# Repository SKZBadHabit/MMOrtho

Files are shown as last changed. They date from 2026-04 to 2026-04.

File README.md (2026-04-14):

# MMOrtho

**Custom 60-key ortholinear keyboard — firmware, hardware, and web configurator**

_Raspberry Pi Pico 2 W · CircuitPython · WiFi · OLED · Browser-based config_

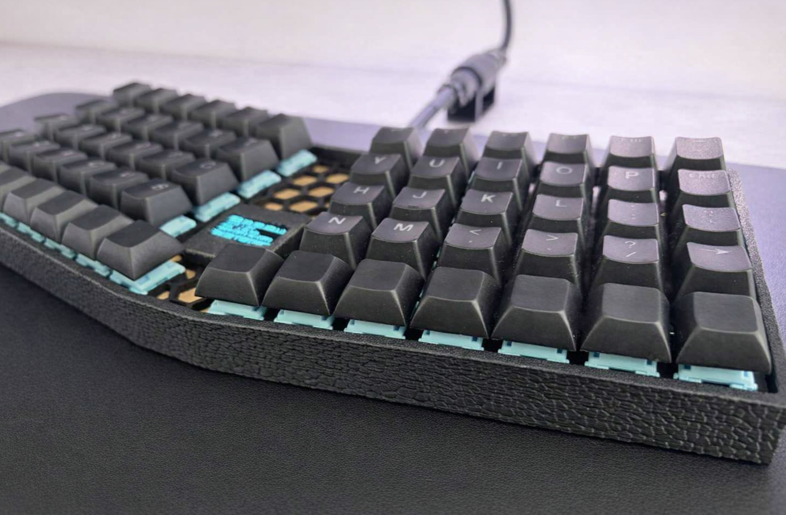
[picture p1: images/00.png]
MMOrtho keyboard


---

## Highlights

- **~1000 Hz scan rate** — rock-solid 9 ms debounce, zero missed keystrokes
- **128×64 OLED dashboard** — 4 live tabs: Status, System, Network, Weather
- **WiFi integrated** — NTP clock, live weather (wttr.in), Home Assistant sync
- **Macro engine** — 8 slots: text strings, key combos, mouse clicks, multi-step sequences
- **Mouse emulation** — left/right buttons, scroll, 100 Hz autoclicker, media controls
- **Web Configurator** — remap keys, edit macros, configure WiFi — all in the browser, no PC tools needed
- **Production-hardened boot** — USB drive and serial disabled by default for security
- **3D-printed case** — full Fusion 360 and STL files included

---

## Hardware

| Component | Spec |
| --- | --- |
| MCU | Raspberry Pi Pico 2 W (RP2350, dual-core @ 150 MHz) |
| Wireless  | CYW43439 2.4 GHz WiFi (onboard) |
| Display | SSD1306 OLED 128×64 px via I2C |
| Matrix | 5 × 12 ortholinear (60 keys) + 2 thumb keys (E18, E19) |
| Scan rate | ~1000 Hz |
| Debounce  | 9 ms |

### Pin Assignments

| Signal | GPIO |
| --- | --- |
| Matrix columns (12) | GP10–GP15, GP16–GP21 |
| Matrix rows (5) | GP0–GP4 |
| Extra key E18 | GP9 |
| Extra key E19 | GP22 |
| Display SDA | GP26 |
| Display SCL | GP27 |

---

## 3D-Printed Case

MMOrtho is a **fully open-source keyboard** — the case is designed to be 3D printed at home.
All CAD files are in the [`hardware/`](hardware/) folder.

| File | Format | Use |
| ---- | --- | --- |
| `MMOrtho.stl` | STL | Standard 3D printing (any slicer) |
| `MMOrtho.3mf` | 3MF | Pre-configured print settings included |
| `MMOrtho.step` | STEP | Import into any CAD tool |
| `MMOrtho.f3d` | Fusion 360 | Fully editable native project |

> **Tip:** Use the `.3mf` file for best results — it includes print orientation and settings.

### Bill of Materials

Everything you need to build one MMOrtho:

| Qty | Part | Notes |
| --- | ---- | ----- |
| 1 | Raspberry Pi Pico 2 W (RP2350) | The RP2350-based W variant with onboard WiFi |
| 1 | SSD1306 OLED Display 128×64 | I2C interface, 4-pin |
| 1 | USB-C Breakout Board | Wired to Pico VBUS/GND for power input |
| 62 | MX-compatible switches | 60 matrix + 2 thumb keys (E18/E19) |
| 62 | Keycaps | MX stem, any profile (e.g. XDA, DSA, OEM) |
| 4 | M3 × 10 mm screws | Case assembly |
| 4 | M3 hex nuts | Case assembly |
| 1 | 3D-printed case | Print from `hardware/MMOrtho.3mf` |

---

## Key Layout

### Base Layer

```
┌────┬───┬───┬───┬───┬───┐           ┌───┬───┬───┬───┬───┬────┐
│ESC │ 1 │ 2 │ 3 │ 4 │ 5 │           │ 6 │ 7 │ 8 │ 9 │ 0 │BSP │
├────┼───┼───┼───┼───┼───┤           ├───┼───┼───┼───┼───┼────┤
│TAB │ Q │ W │ E │ R │ T │           │ Y │ U │ I │ O │ P │ \  │
├────┼───┼───┼───┼───┼───┤           ├───┼───┼───┼───┼───┼────┤
│LTG │ A │ S │ D │ F │ G │           │ H │ J │ K │ L │ ; │ '  │
├────┼───┼───┼───┼───┼───┤           ├───┼───┼───┼───┼───┼────┤
│SFT │ Z │ X │ C │ V │ B │           │ N │ M │ , │ . │ / │SFT │
├────┼───┼───┼───┼───┼───┼───────────┼───┼───┼───┼───┼───┼────┤
│CTL │WIN│ALT│AGR│SPC│FN │ E19   E18 │SPC│ENT│ ^ │ = │ [ │ ]  │
└────┴───┴───┴───┴───┴───┴───────────┴───┴───┴───┴───┴───┴────┘
```

### FN Layer (hold FN)

| Shortcut | Action | Shortcut | Action |
| --- | --- | --- | --- |
| FN + I/K/J/L | Arrow keys | FN + W | WiFi toggle |
| FN + R / F | Scroll up / down | FN + , | WiFi Setup Wizard |
| FN + B / G | Mouse left / right click | FN + . | Cycle OLED tab |
| FN + A | Autoclicker toggle | FN + [ / ] | Volume down / up  |
| FN + M | Mute | FN + P | System reset |
| FN + O | Page Up | FN + ; | Show statistics |
| FN + E18 | Web Configurator | | |

---

## OLED Dashboard

Switch tabs with **FN + .**

| Tab | Content |
| --- | --- |
| **STS** | KPM, uptime, Caps Lock, autoclicker state, WiFi, CPU temp |
| **SYS** | Live bars — CPU temp, voltage, scan rate |
| **NET** | WiFi signal, Home Assistant entity states |
| **WTR** | NTP clock with auto-DST + local weather from wttr.in |

---

## Boot Modes

| Mode | Trigger | USB Drive | USB Serial | HID |
| --- | --- | --- | --- | --- |
| Production  | Normal plug-in | Off | Off | On  |
| Development | Hold E18 at plug-in | On | On | On  |

> **Note:** Never use Development mode in public — the full firmware filesystem is exposed via USB mass storage.

---

## Macro Engine

Create macros in the Web Configurator and assign them to any key (M1–M8).

| Type | Description |
| --- | --- |
| **Text** | Types a string character by character |
| **Combo** | Presses multiple keys simultaneously (e.g. Ctrl+Shift+T) |
| **Mouse** | Fires a mouse button click or scroll action |
| **Sequence** | Multi-step: mix text, combos, mouse actions, and delays  |

---

## Web Configurator

Activate with **FN + M** (WiFi must be connected).
Open the IP shown on the OLED in any browser on the same network.

| Tab | What you can do |
| --- | --- |
| Docs | Full documentation rendered live |
| Keymap | Remap all keys across Base and FN layers |
| Macros | Create, edit, delete macros — all 4 types |
| Settings | Timing, Home Assistant, weather, NTP timezone |
| Network | Scan and connect to WiFi networks |
| Statistics | All-time keypresses, runtime, KPM, IP address |

---

## Power Management

| Level | Trigger | Effect |
| --- | --- | --- |
| Display sleep | 210 s idle | OLED turns off |
| Deep idle | 30 min idle  | WiFi off, scan rate reduced |
| Wake | Any keypress | Instant full restore |

---

## Repository Structure

```
MMOrtho/
├── firmware/               # CircuitPython source code
│   ├── boot.py             # Boot mode selector
│   ├── code.py             # Main entry point & async event loop
│   ├── config.py           # Hardware pins, timing, API config
│   ├── keymap.py           # QMK-style layer definitions
│   ├── i2cdisplaybus.py    # Display bus compatibility wrapper
│   ├── features/           # Modular feature system
│   │   ├── keyboard.py     # Matrix scanning engine
│   │   ├── display.py      # OLED dashboard (4 tabs)
│   │   ├── macros.py       # Macro engine
│   │   ├── webserver.py    # HTTP server + REST API
│   │   ├── wifi.py         # WiFi, NTP, weather, Home Assistant
│   │   ├── mouse.py        # Mouse emulation & autoclicker
│   │   ├── power.py        # Power management & sleep
│   │   └── storage.py      # JSON-based persistent statistics
│   └── web/
│       └── index.html      # Web Configurator (single-page app)
│
├── hardware/               # 3D CAD files
│   ├── MMOrtho.3mf         # 3MF — optimized for 3D printing
│   ├── MMOrtho.stl         # STL — standard 3D printing format
│   ├── MMOrtho.step        # STEP — CAD-agnostic exchange format
│   └── MMOrtho.f3d         # Fusion 360 native project
│
├── libs/                   # CircuitPython library dependencies
│   └── (adafruit libraries — copy to CIRCUITPY/lib/)
│
├── images/                 # Product photos
│
└── docs/
    ├── SETUP.md            # Step-by-step installation guide
    └── TROUBLESHOOTING.md  # Common issues and fixes
```

---

## Getting Started

See [docs/SETUP.md](docs/SETUP.md) for the full installation guide.

**Quick summary:**

1. Flash CircuitPython to Pico 2 W
2. Copy `libs/` → `CIRCUITPY/lib/`
3. Copy `firmware/` contents → `CIRCUITPY/`
4. Edit `config.py` with your Home Assistant URL/token and city
5. Plug in — keyboard is ready
6. Use **FN + ,** to connect WiFi via the interactive wizard

---

## Photos

<table>
<tr>
<td>MMOrtho front view</td>
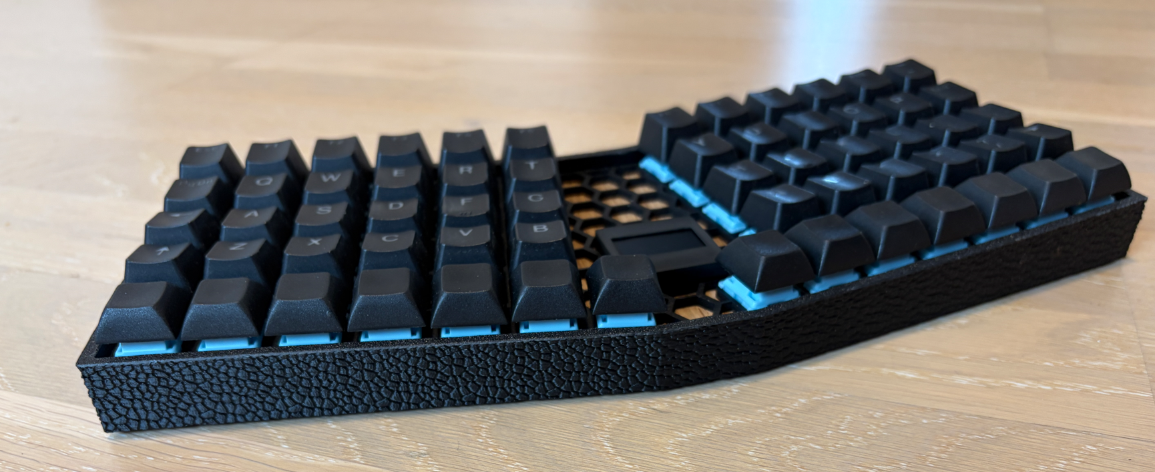
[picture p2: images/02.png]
MMOrtho side view
<td></td>
</tr>
<tr>
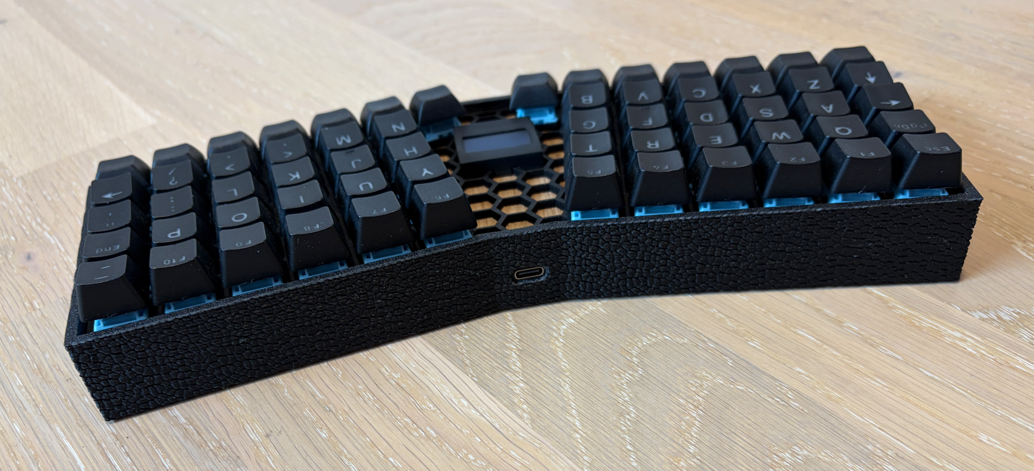
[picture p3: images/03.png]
MMOrtho OLED display
<td></td>
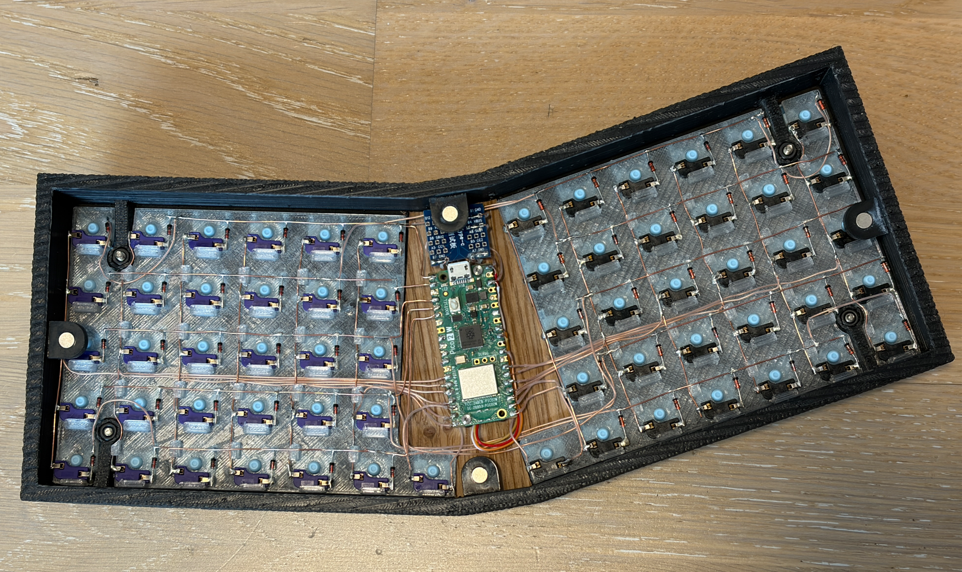
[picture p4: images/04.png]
MMOrtho internals
<td></td>
</tr>
<tr>
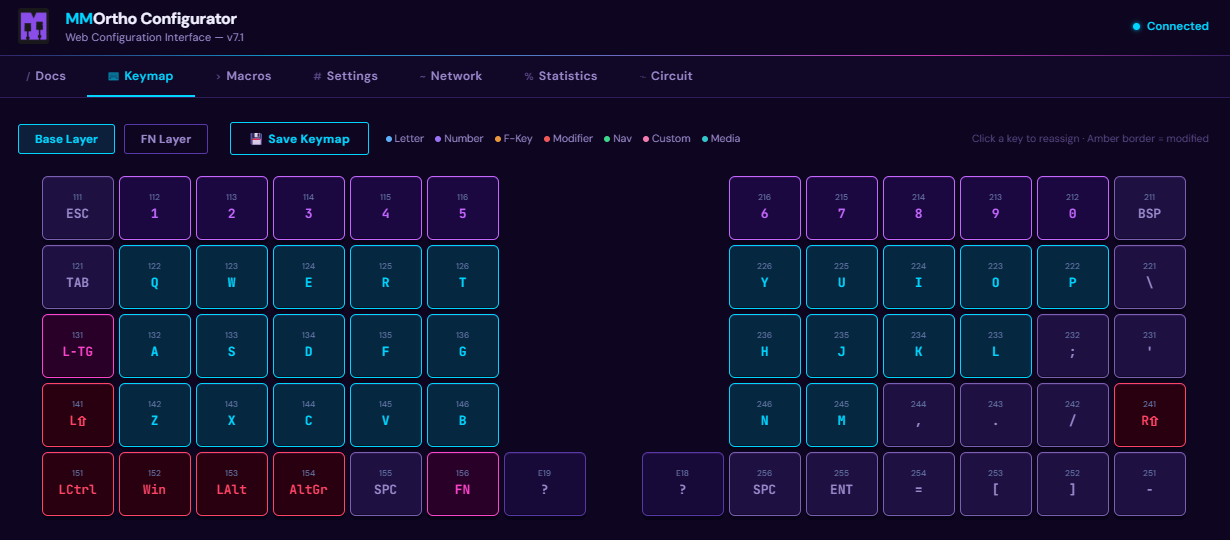
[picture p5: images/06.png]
Hand-wiring detail
<td></td>
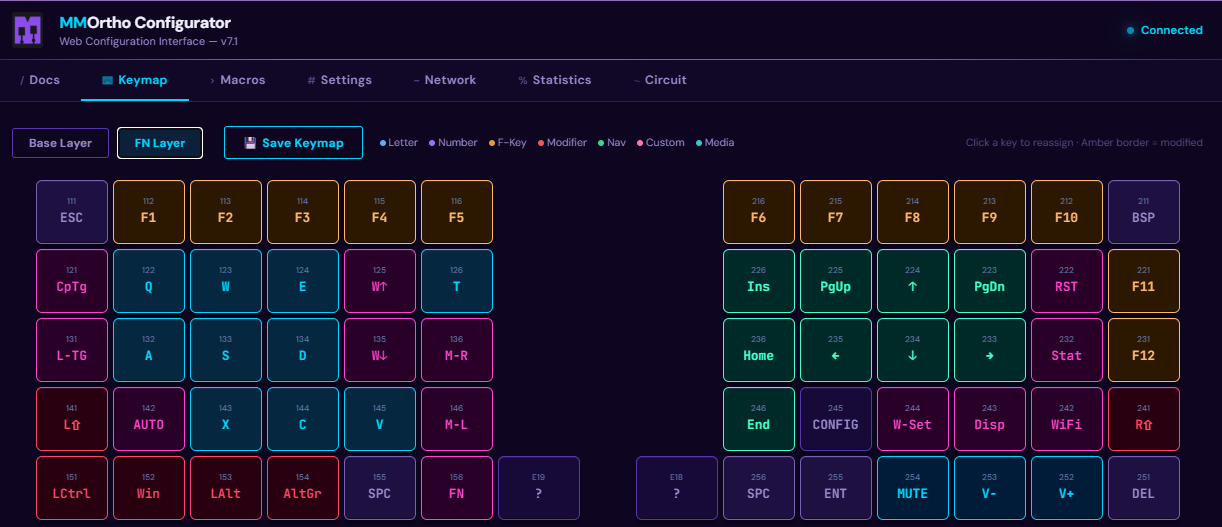
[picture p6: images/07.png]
Kailh Hotswap Socket clips
<td></td>
</tr>
<tr>
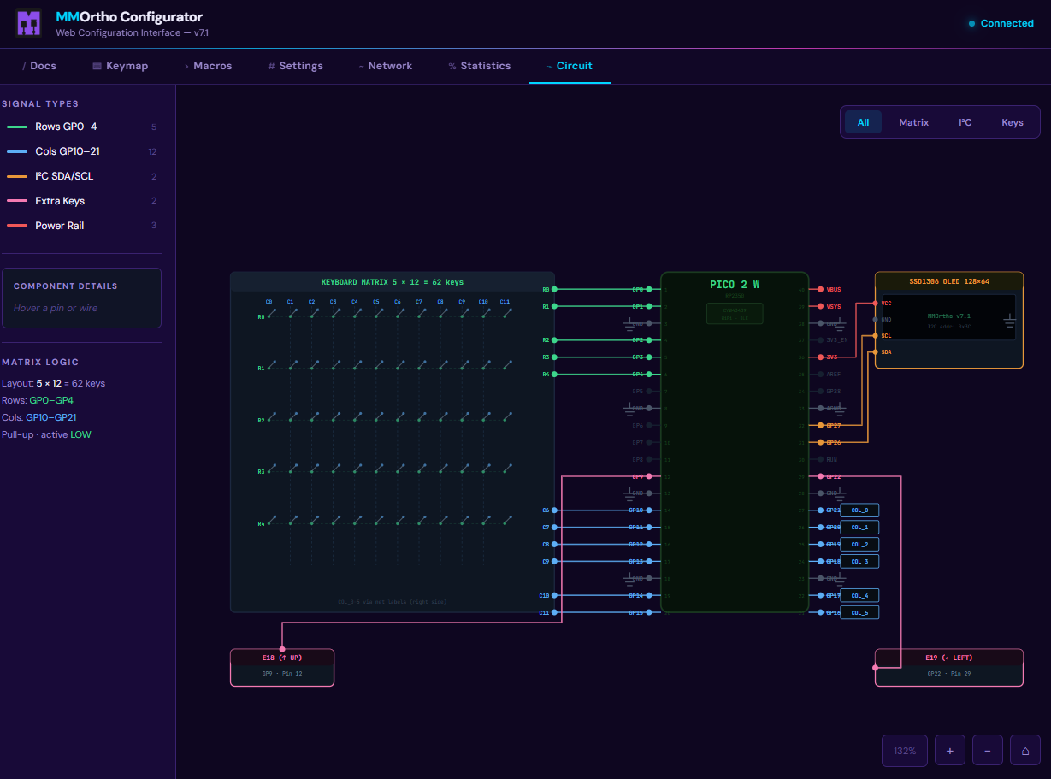
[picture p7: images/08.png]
Assembled keyboard profile
<td colspan="2" align="center"></td>
</tr>
</table>

---

## License

MIT License — see [LICENSE](LICENSE) for details.

Developed by **Bad Habit**

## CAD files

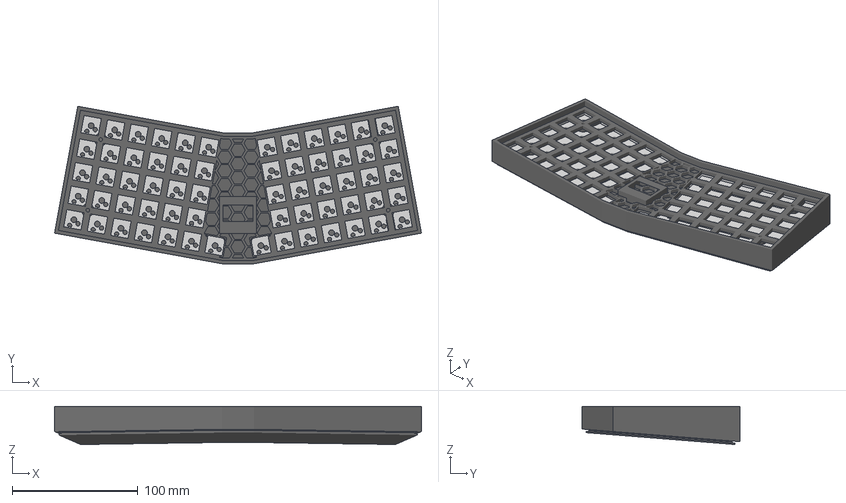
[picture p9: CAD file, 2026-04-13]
hardware/MMOrtho.3mf
292.4 x 125.5 x 30.3 mm
Aussen
BasePlate
BasePlateHalter (1) (1)
BasePlateHalter (1)
BasePlateHalter (2)
BasePlateHalter
Boden
DisplayWabe_neueDisplays
FullPlate_left
FullPlate_right (1)
Innen
PCB-Distanzhalter_Right
PCB-Distanzhalter_left
Pi_Pico_Glue_Mount_-_Plate
USB_inlay
WabenBackground

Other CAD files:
hardware/MMOrtho.stl

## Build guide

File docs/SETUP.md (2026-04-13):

# Setup Guide

## Requirements

- Raspberry Pi Pico 2 W (RP2350)
- SSD1306 OLED display (128×64, I2C)
- Custom PCB or hand-wired 5×12 matrix + 2 thumb keys
- USB-C cable for flashing

---

## Step 1 — Flash CircuitPython

1. Download the latest **CircuitPython UF2** for Raspberry Pi Pico 2 W from:
   [circuitpython.org/board/raspberry_pi_pico2_w](https://circuitpython.org/board/raspberry_pi_pico2_w)

2. Hold the **BOOTSEL** button on the Pico 2 W and plug it into USB.
   The device mounts as `RPI-RP2`.

3. Drag & drop the `.uf2` file onto `RPI-RP2`.
   The Pico reboots and mounts as `CIRCUITPY`.

---

## Step 2 — Install Libraries

Copy the entire `libs/` folder from this repository to the `lib/` folder on `CIRCUITPY`:

```
CIRCUITPY/
└── lib/
    ├── adafruit_hid/
    ├── adafruit_httpserver/
    ├── adafruit_display_text/
    ├── adafruit_display_shapes/
    ├── adafruit_displayio_ssd1306.mpy
    ├── adafruit_connection_manager.mpy
    ├── adafruit_matrixkeypad.mpy
    ├── adafruit_requests.mpy
    ├── adafruit_ntp.mpy
    ├── adafruit_ticks.mpy
    └── asyncio/
```

---

## Step 3 — Configure the Firmware

1. Copy `firmware/config.py` to `CIRCUITPY/config.py`.

2. Edit `config.py` and set your values:

   | Setting | Description |
   |---------|-------------|
   | `HomeAssistant.URL` | Your Home Assistant IP and port |
   | `HomeAssistant.TOKEN` | Long-Lived Access Token (HA → Profile → Security) |
   | `HomeAssistant.ENTITIES` | Entity IDs to monitor on the NET tab |
   | `WeatherConfig.CITY` | Your city name for wttr.in weather |
   | `WeatherConfig.NTP_TZ_OFFSET` | UTC offset (e.g. `1` for CET, `2` for CEST) |

   > Home Assistant integration is optional — leave TOKEN empty to disable it.

---

## Step 4 — Copy Firmware Files

Copy these files/folders from `firmware/` to the root of `CIRCUITPY`:

```
CIRCUITPY/
├── boot.py
├── code.py
├── config.py          ← your edited version
├── keymap.py
├── i2cdisplaybus.py
├── features/
└── web/
```

---

## Step 5 — First Boot

Unplug and replug the keyboard (without holding any key).

The keyboard boots in **Production Mode**:
- USB drive is hidden
- USB serial is disabled
- USB HID is active — the keyboard works immediately

---

## Step 6 — WiFi Setup

1. Hold **FN** and press **,** (comma) to start the WiFi Setup Wizard.
2. The OLED display guides you through entering your SSID and password using the keyboard.
3. Credentials are saved encrypted to `/data/wifi.json` on the device.

---

## Step 7 — Web Configurator

1. Make sure WiFi is connected (NET tab shows an IP address).
2. Hold **FN** and press **E18** to start Config Mode.
3. Open a browser on any device on the same network and go to the IP shown on the OLED.
4. The Web Configurator loads — remap keys, create macros, adjust settings.

---

## Development Mode

To edit firmware files after first setup:

1. Hold **E18** and plug the keyboard into USB.
2. The keyboard boots in **Development Mode** — `CIRCUITPY` drive and USB serial are accessible.
3. Edit files normally. CircuitPython auto-restarts on save.
4. Unplug and replug (without holding E18) to return to Production Mode.

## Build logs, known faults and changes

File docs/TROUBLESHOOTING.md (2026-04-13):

# Troubleshooting

## Keyboard not recognized as HID device

**Symptom:** PC shows no keyboard after plugging in.

- Make sure you booted in **Production Mode** (no key held at plug-in).
- Verify `boot.py` is on `CIRCUITPY` root.
- Check that `adafruit_hid` library is in `lib/`.

---

## OLED display stays blank

**Symptom:** Display never lights up.

- Verify I2C wiring: SDA → GP26, SCL → GP27.
- Confirm the display address is `0x3C` (scan with `import busio; i2c = busio.I2C(...); i2c.scan()`).
- Check that `adafruit_displayio_ssd1306.mpy` is in `lib/`.

---

## WiFi not connecting

**Symptom:** WiFi icon shows disconnected, no IP on NET tab.

- Run the **WiFi Setup Wizard** again: **FN + ,**
- Ensure the SSID is 2.4 GHz (Pico 2 W does not support 5 GHz).
- Delete `/data/wifi.json` from CIRCUITPY (Development Mode) and re-run the wizard.

---

## Web Configurator not loading

**Symptom:** Browser shows "connection refused" or times out.

- WiFi must be connected first — check NET tab for an IP.
- Make sure `web/index.html` is on `CIRCUITPY/web/index.html`.
- Check `adafruit_httpserver` is in `lib/`.
- Try a different browser or disable browser extensions.

---

## Keys not registering / wrong keys

**Symptom:** Key presses are missed or wrong character appears.

- Check matrix wiring matches the pin assignments in `config.py`.
- Verify the keymap in `keymap.py` matches your physical layout.
- Use the **Web Configurator → Keymap** tab to remap keys without editing code.

---

## Home Assistant entities not showing

**Symptom:** NET tab shows `--` for entity states.

- Verify `HomeAssistant.URL` and `HomeAssistant.TOKEN` in `config.py`.
- Generate a new Long-Lived Access Token in HA: **Profile → Security → Long-Lived Access Tokens**.
- Check that entity IDs in `HomeAssistant.ENTITIES` exactly match those in HA.

---

## Firmware crash / constant reboot loop

**Symptom:** OLED flickers, keyboard constantly resets.

1. Boot into **Development Mode** (hold E18 at plug-in).
2. Open a serial terminal (115200 baud) — e.g. Thonny or `screen /dev/ttyACM0 115200`.
3. Read the traceback printed to serial.
4. Fix the offending file and save — CircuitPython restarts automatically.

---

## Out of memory (MemoryError)

**Symptom:** Serial shows `MemoryError` after boot.

- Make sure all `.py` files in `features/` are not accidentally duplicated.
- Check for runaway string concatenation in macros or display code.
- The GC interval in `config.py` (`Timing.GC_INTERVAL`) can be lowered for more frequent collection.

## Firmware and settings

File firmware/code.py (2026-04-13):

# code.py - MMOrtho Keyboard Main Entry Point
# Modular Firmware for CircuitPython
#
# Version: 5.0
# Hardware: Raspberry Pi Pico2 W (RP2350)
# Author: Michael Mörtenhuber
#
# v5.0 Changes:
#   - Modern Dashboard UI with 3 switchable panels
#   - Redesigned Splash Screen
#   - Performance optimizations in main loop

import asyncio
import time
import traceback
import usb_hid
from adafruit_hid.keyboard import Keyboard
from adafruit_hid.mouse import Mouse
from adafruit_hid.consumer_control import ConsumerControl

# Config & Keymap
from config import KEYBOARD_NAME, CODE_VERSION, WeatherConfig
from keymap import KC

# Features
from features.keyboard import KeyboardEngine
from features.display import DisplayFeature, MODE_NETWORK
from features.storage import StorageFeature
from features.wifi import WiFiFeature
from features.mouse import MouseFeature
from features.power import PowerFeature
from features.webserver import WebServerFeature
from features.macros import MacroEngine


# =============================================================================
# HID SETUP
# =============================================================================

kbd = Keyboard(usb_hid.devices)
hid_mouse = Mouse(usb_hid.devices)
cc = ConsumerControl(usb_hid.devices)


# =============================================================================
# FEATURE INITIALIZATION
# =============================================================================

# Core Features
keyboard = KeyboardEngine(kbd)
display = DisplayFeature()
storage = StorageFeature()

# Optional Features
wifi = WiFiFeature()
mouse = MouseFeature(hid_mouse, cc)
power = PowerFeature(display, storage, wifi)
macro_engine = MacroEngine(kbd, hid_mouse)
webserver = WebServerFeature(wifi, storage, macro_engine)


# =============================================================================
# FEATURE WIRING (Connect Features Together)
# =============================================================================

def on_keypress():
    """Callback bei jedem Tastendruck"""
    storage.increment_keypress()
    power.activity()

    # Display State aktualisieren
    display.set_state("current_keypress", storage.current_keypress)


def on_layer_change(layer, toggled=False):
    """Callback bei Layer-Wechsel"""
    display.update_layer(layer, toggled)


def on_autoclicker_change(enabled):
    """Callback bei Autoclicker Toggle"""
    display.set_state("autoclicker", enabled)


def on_caps_change():
    """Callback bei Caps Lock Toggle"""
    display.update_caps(keyboard.caps_on)


# Wire up Callbacks
keyboard.on_keypress = on_keypress
keyboard.on_layer_change = on_layer_change
mouse.on_autoclicker_change = on_autoclicker_change


# =============================================================================
# CUSTOM KEY HANDLERS
# =============================================================================

def handle_mouse_left():
    """Handler für Mausklick links (Hold)"""
    mouse.left_press()


def handle_mouse_right():
    """Handler für Mausklick rechts (Hold)"""
    mouse.right_press()


def handle_show_stats():
    """Handler für Statistik-Anzeige"""
    storage.force_save()
    wifi.refresh_device_status()
    display.show_statistics(
        storage.alltime_keypress,
        storage.alltime_runtime,
        wifi.get_ip_address()
    )


def handle_display_mode():
    """Handler für Display-Modus Toggle"""
    display.toggle_mode()


def handle_wifi_toggle():
    """Handler für WiFi Toggle"""
    wifi.toggle()
    # Status an Display weitergeben
    status = wifi.get_status_dict()
    for key, value in status.items():
        display.set_state(key, value)


def handle_wifi_setup():
    """Handler für WiFi Setup Wizard (FN+,)"""
    if wifi.setup_active:
        return  # Wizard läuft bereits
    wifi.start_setup()
    keyboard.key_interceptor = wifi.handle_setup_key


def handle_config_mode():
    """
    Handler für FN + Right Shift → Configuration Mode Toggle.
    Im Config Mode zeigt das Display 'Configuration Mode' + IP-Adresse.
    Tastatur arbeitet normal weiter, nur das Display ändert sich.
    Zweiter Druck auf FN + Right Shift kehrt zum normalen Dashboard zurück.

    KEIN wifi.start_ap() hier — AP-Init blockiert 3-10s und friert die
    Tastatur ein. Config Mode setzt WiFi voraus (Setup-Wizard: FN+,).
    """
    if display.config_mode_active:
        # Config Mode beenden
        display.exit_config_mode()
        webserver.stop()
    else:
        # Config Mode aktivieren — nur wenn WiFi verbunden
        ip = wifi.get_ip_address()
        if ip == "Not connected":
            # Kein WiFi → Display-Hinweis aber kein Freeze durch AP-Init
            display.show_config_mode(None)
        else:
            display.show_config_mode(ip)
            webserver.start()


# Register Custom Key Handlers
keyboard.register_handler(KC.MOUSE_LEFT, handle_mouse_left)
keyboard.register_handler(KC.MOUSE_RIGHT, handle_mouse_right)
keyboard.register_handler(KC.MOUSE_WHEEL_UP, mouse.scroll_up)
keyboard.register_handler(KC.MOUSE_WHEEL_DOWN, mouse.scroll_down)
keyboard.register_handler(KC.AUTOCLICKER, mouse.toggle_autoclicker)
keyboard.register_handler(KC.WIFI_TOGGLE, handle_wifi_toggle)
keyboard.register_handler(KC.WIFI_SETUP, handle_wifi_setup)
keyboard.register_handler(KC.DISPLAY_MODE, handle_display_mode)
keyboard.register_handler(KC.SHOW_STATS, handle_show_stats)
keyboard.register_handler(KC.SYSTEM_RESET, storage.save_and_reset)
keyboard.register_handler(KC.CAPS_TOGGLE, on_caps_change)
keyboard.register_handler(KC.MUTE, mouse.mute)
keyboard.register_handler(KC.VOL_DOWN, mouse.volume_down)
keyboard.register_handler(KC.VOL_UP, mouse.volume_up)
keyboard.register_handler("KC_CONFIG_MODE", handle_config_mode)

# Macro Handlers (KC.MACRO_1 .. KC.MACRO_8 → macro IDs 1-8)
keyboard.register_handler(KC.MACRO_1, lambda: macro_engine.execute(1))
keyboard.register_handler(KC.MACRO_2, lambda: macro_engine.execute(2))
keyboard.register_handler(KC.MACRO_3, lambda: macro_engine.execute(3))
keyboard.register_handler(KC.MACRO_4, lambda: macro_engine.execute(4))
keyboard.register_handler(KC.MACRO_5, lambda: macro_engine.execute(5))
keyboard.register_handler(KC.MACRO_6, lambda: macro_engine.execute(6))
keyboard.register_handler(KC.MACRO_7, lambda: macro_engine.execute(7))
keyboard.register_handler(KC.MACRO_8, lambda: macro_engine.execute(8))


# =============================================================================
# DISPLAY STATE SYNC
# =============================================================================

def sync_display_state():
    """Synchronisiert alle State-Werte mit dem Display"""
    display.set_state("cpu_temp", power.get_cpu_temp())
    display.set_state("scan_rate", keyboard.scan_rate)
    display.set_state("autoclicker", mouse.autoclicker_on)
    display.set_state("voltage", power.get_voltage())
    display.set_state("caps_on", keyboard.caps_on)
    display.set_state("current_runtime", storage.get_live_runtime())

    # WiFi Status
    status = wifi.get_status_dict()
    for key, value in status.items():
        display.set_state(key, value)


# =============================================================================
# MAIN LOOP
# =============================================================================

async def main():
    """Haupt-Async-Loop - Optimized for v5.0"""
    print(f"\n{KEYBOARD_NAME} v{CODE_VERSION} starting...")

    # Splash Screen anzeigen
    display.splash_screen()

    # Warten auf Tastendruck
    print("Waiting for keypress...")
    keyboard.wait_for_keypress()

    # Main Screen aktivieren
    display.main_screen()
    sync_display_state()

    # Webserver Task starten
    asyncio.create_task(webserver.run_async())

    print("Keyboard active!")

    # === Timer Initialization ===
    current_time = time.monotonic()
    last_display_update = current_time
    last_runtime_update = current_time
    last_scroll_time = current_time
    last_weather_update = -WeatherConfig.REFRESH_INTERVAL  # Sofort beim ersten Loop holen

    # === Constants (avoid repeated lookups) ===
    SCROLL_REPEAT_INTERVAL = 0.05  # 50ms = 20 scrolls/sec
    DISPLAY_UPDATE_INTERVAL = 30.0
    RUNTIME_UPDATE_INTERVAL = 300.0

    # Cache key strings for faster comparison
    KEY_MOUSE_LEFT = "146"
    KEY_MOUSE_RIGHT = "136"
    KEY_SCROLL_UP = "125"
    KEY_SCROLL_DOWN = "135"

    # Main Loop
    while True:
        # Zeit einmal pro Loop holen (single call per iteration)
        current_time = time.monotonic()

        # === HIGH PRIORITY: Keyboard Processing ===
        keyboard.process()

        # === WiFi Setup Wizard ===
        if wifi.setup_active:
            wifi.update_setup(display)
            # Wizard gerade beendet → aufräumen
            if not wifi.setup_active:
                keyboard.key_interceptor = None
                display.main_screen()
                display.needs_update = True
                for k, v in wifi.get_status_dict().items():
                    display.set_state(k, v)
            continue  # Rest des Loops überspringen während Setup aktiv
        elif keyboard.key_interceptor is not None:
            # Wizard durch ESC-Taste beendet (handle_setup_key setzte _DONE
            # bevor dieser Check läuft → setup_active ist bereits False)
            keyboard.key_interceptor = None
            display.main_screen()
            display.needs_update = True
            for k, v in wifi.get_status_dict().items():
                display.set_state(k, v)

        # === Mouse Release Handling ===
        pressed = keyboard.pressed_keys  # Cache reference
        if mouse.left_held and KEY_MOUSE_LEFT not in pressed:
            mouse.left_release()
        if mouse.right_held and KEY_MOUSE_RIGHT not in pressed:
            mouse.right_release()

        # === Scroll Repeat (Layer 1 only) ===
        if keyboard.current_layer == 1:
            scroll_delta = current_time - last_scroll_time
            if scroll_delta >= SCROLL_REPEAT_INTERVAL:
                if KEY_SCROLL_UP in pressed:
                    mouse.scroll_up()
                    last_scroll_time = current_time
                elif KEY_SCROLL_DOWN in pressed:
                    mouse.scroll_down()
                    last_scroll_time = current_time

        # === Autoclicker ===
        mouse.handle_autoclicker()

        # === Background Tasks ===
        power.check()

        # === Display Updates (throttled) ===
        display_delta = current_time - last_display_update
        if display_delta >= DISPLAY_UPDATE_INTERVAL:
            # Batch state updates to reduce overhead
            display.set_state("cpu_temp", power.get_cpu_temp())
            display.set_state("scan_rate", keyboard.scan_rate)
            display.set_state("voltage", power.get_voltage())

            # WiFi Status (only if enabled)
            if wifi.enabled:
                # HA-Status nur abrufen wenn NET-Tab aktiv (blockierende HTTP-Calls)
                if display.mode == MODE_NETWORK:
                    wifi.refresh_device_status()
                for key, value in wifi.get_status_dict().items():
                    display.set_state(key, value)

            last_display_update = current_time

        # Wetter-Update (alle WeatherConfig.REFRESH_INTERVAL Sekunden, nur wenn WiFi aktiv)
        if wifi.enabled and (current_time - last_weather_update >= WeatherConfig.REFRESH_INTERVAL):
            weather = wifi.fetch_weather()
            if weather:
                display.set_state("weather_temp", weather["temp"])
                display.set_state("weather_hum",  weather["hum"])
                display.set_state("weather_cond", weather["cond"])
                display.set_state("weather_city", weather["city"])
            display.set_state("ntp_synced", wifi.ntp_synced)
            last_weather_update = current_time

        # === Runtime Update (every 5 min) ===
        if current_time - last_runtime_update >= RUNTIME_UPDATE_INTERVAL:
            display.set_state("current_runtime", storage.get_live_runtime())
            last_runtime_update = current_time

        # === Display Refresh ===
        display.refresh()

        # Sleep: 1ms normal, 50ms im Deep Idle (CPU schont sich)
        await asyncio.sleep(power.get_loop_sleep())


# =============================================================================
# ENTRY POINT
# =============================================================================

if __name__ == "__main__":
    print("=" * 40)
    print(f"  {KEYBOARD_NAME}")
    print(f"  Firmware v{CODE_VERSION}")
    print("=" * 40)

    # Initial Load
    storage.load()

    # Run Main Loop
    try:
        asyncio.run(main())
    except KeyboardInterrupt:
        print("\nShutdown requested")
    except Exception as e:
        print(f"Error: {e}")
        traceback.print_exception(type(e), e, e.__traceback__)
    finally:
        print("Goodbye!")

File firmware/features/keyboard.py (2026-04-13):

# features/keyboard.py - Keyboard Matrix Scanning & Key Processing
# QMK-Style Keyboard Engine
import time
import digitalio
import adafruit_matrixkeypad
from adafruit_hid.keycode import Keycode

from config import MATRIX_COLS, MATRIX_ROWS, EXTRA_KEYS, Timing
from keymap import LAYERS, MATRIX_KEYS, KC, EXTRA_KEYS_CONFIG


class KeyboardEngine:
    """
    Zentrale Keyboard-Engine für Matrix-Scanning und Key-Processing.
    Inspiriert von QMK's quantum/matrix.c und process_record.
    """

    def __init__(self, hid_keyboard):
        self.kbd = hid_keyboard
        self.current_layer = 0
        self.fn_active = False
        self.pressed_keys = set()
        self.last_scan_time = time.monotonic()

        # Modifier Tracking
        self.shift_active = False
        self.altgr_active = False
        self.caps_on = False
        self.layer_toggled = False  # True wenn Layer per Toggle gewechselt wurde

        # Scan Rate Tracking
        self._scan_count = 0
        self._scan_rate_time = time.monotonic()
        self._scan_rate = 0  # Scans pro Sekunde

        # Custom Key Handlers (registriert von außen)
        self.handlers = {}

        # Key Interceptor (z.B. für WiFi Setup Wizard)
        # Wenn gesetzt: fn(key_str, base_action, shift_active) → alle Keys werden
        # an diesen Callback weitergeleitet, keine HID-Events gesendet.
        self.key_interceptor = None

        # Callbacks für Events
        self.on_keypress = None  # Callback bei jedem Tastendruck
        self.on_layer_change = None  # Callback bei Layer-Wechsel

        # Hardware Init
        self._init_matrix()
        self._init_extra_keys()
        self._init_non_us_keycode()

    def _init_matrix(self):
        """Initialisiert die Tastatur-Matrix"""
        try:
            # Columns als Output
            self.cols = []
            for pin in MATRIX_COLS:
                col = digitalio.DigitalInOut(pin)
                col.direction = digitalio.Direction.OUTPUT
                self.cols.append(col)

            # Rows als Input mit Pull-Down
            self.rows = []
            for pin in MATRIX_ROWS:
                row = digitalio.DigitalInOut(pin)
                row.direction = digitalio.Direction.INPUT
                row.pull = digitalio.Pull.DOWN
                self.rows.append(row)

            # Matrix Keypad erstellen
            self.keypad = adafruit_matrixkeypad.Matrix_Keypad(
                self.rows, self.cols, MATRIX_KEYS
            )
        except Exception as e:
            print(f"Matrix Init Error: {e}")
            raise  # Kritischer Fehler – Keyboard nicht nutzbar ohne Matrix

    def _init_extra_keys(self):
        """Initialisiert Extra-Keys außerhalb der Matrix"""
        self.extra_switches = {}
        for key_name, pin in EXTRA_KEYS.items():
            try:
                switch = digitalio.DigitalInOut(pin)
                switch.direction = digitalio.Direction.INPUT
                switch.pull = digitalio.Pull.UP
                self.extra_switches[key_name] = switch
            except Exception as e:
                print(f"Extra Key Init Error ({key_name}): {e}")

    def _init_non_us_keycode(self):
        """Initialisiert NON_US Keycode mit Fallback"""
        try:
            self.non_us = Keycode.NON_US_BACKSLASH
        except AttributeError:
            try:
                self.non_us = Keycode.NON_US_HASH
            except AttributeError:
                self.non_us = 0x64

    def register_handler(self, key_code, handler_fn):
        """
        Registriert einen Handler für Custom Keycodes.

        Args:
            key_code: Der Custom Keycode (z.B. KC.WIFI_TOGGLE)
            handler_fn: Die aufzurufende Funktion
        """
        self.handlers[key_code] = handler_fn

    def process(self):
        """
        Hauptfunktion - scannt Matrix und verarbeitet Keys.
        Sollte in der Main-Loop aufgerufen werden.
        """
        current_time = time.monotonic()

        # Debounce Check
        if current_time - self.last_scan_time < Timing.DEBOUNCE:
            return

        # Matrix scannen
        matrix_keys = [str(k) for k in self.keypad.pressed_keys]

        # Extra Keys scannen
        extra_keys = []
        for key_name, switch in self.extra_switches.items():
            if not switch.value:  # Pull-Up, also LOW = gedrückt
                extra_keys.append(key_name)

        all_keys = matrix_keys + extra_keys

        # Process Presses (Callback wird dort nur bei NEUEN Keys aufgerufen)
        self._process_presses(all_keys)

        # Process Releases
        self._process_releases(all_keys)

        self.last_scan_time = current_time

        # Scan Rate berechnen (alle 1 Sekunde aktualisieren)
        self._scan_count += 1
        if current_time - self._scan_rate_time >= 1.0:
            self._scan_rate = self._scan_count
            self._scan_count = 0
            self._scan_rate_time = current_time
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

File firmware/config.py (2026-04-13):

# config.py - Hardware & Timing Konfiguration (QMK-Style config.h)
# MMOrtho Keyboard Configuration
import board

# === KEYBOARD INFO ===
KEYBOARD_NAME = "MMOrtho"
MODEL_NUMBER = "4-01"
CODE_VERSION = "7.1"

# === MATRIX PINS ===
# Spalten (Columns) - Output
MATRIX_COLS = [
    board.GP21, board.GP20, board.GP19, board.GP18, board.GP17, board.GP16,
    board.GP10, board.GP11, board.GP12, board.GP13, board.GP14, board.GP15
]

# Zeilen (Rows) - Input mit Pull-Down
MATRIX_ROWS = [board.GP0, board.GP1, board.GP2, board.GP3, board.GP4]

# === EXTRA KEYS (außerhalb der Matrix) ===
EXTRA_KEYS = {
    "E18": board.GP9,   # ^ / ° Taste (rechts)
    "E19": board.GP22,  # < > | Taste (links)
}

# === DISPLAY I2C ===
DISPLAY_SDA = board.GP26
DISPLAY_SCL = board.GP27
DISPLAY_I2C_ADDRESS = 0x3C
DISPLAY_WIDTH = 128
DISPLAY_HEIGHT = 64

# === TIMING (in Sekunden) ===
class Timing:
    DEBOUNCE = 0.009              # 9ms Debounce für stabile Erkennung
    ENERGY_SAVE_TIMEOUT = 210     # Display aus nach 210s Inaktivität
    DEEP_IDLE_TIMEOUT = 1800      # Deep Idle nach 30min (WiFi aus, Loop 50ms)
    GC_INTERVAL = 910             # Garbage Collection alle 910s
    DISPLAY_REFRESH = 61          # Display-Refresh alle 61s
    AUTOCLICKER_INTERVAL = 0.01   # 10ms = 100 Klicks/Sekunde
    AUTOCLICKER_DEBOUNCE = 0.3    # 300ms Toggle-Debounce
    VOLTAGE_REFRESH = 5           # Spannung alle 5s messen

# === STORAGE PATHS ===
class Storage:
    DATA_DIR = "/data"
    STATS_FILE = "/data/stats.json"

    # Legacy-Dateien für Migration (werden nicht mehr verwendet)
    RUNTIME_FILE_LEGACY = "/runtime.txt"
    KEYPRESS_FILE_LEGACY = "/keypress.txt"

# === WIFI / HOME ASSISTANT ===
class HomeAssistant:
    URL = "http://YOUR_HA_IP:8123"                   # e.g. "http://192.168.1.100:8123"
    TOKEN = "YOUR_LONG_LIVED_ACCESS_TOKEN"           # HA Profile → Long-Lived Access Tokens
    ENTITIES = {
        # Map a short name to a Home Assistant entity_id
        # These are shown on the NET display tab
        # "laser": "switch.lasercutter",
        # "printer_3d": "switch.3d_strom",
    }

class WeatherConfig:
    """Wetter und NTP Konfiguration"""
    CITY = "Vienna"                  # Stadt fuer wttr.in Abfrage
    ENABLED = True                  # False = kein Wetter-Fetch
    REFRESH_INTERVAL = 600          # Sekunden zwischen Wetter-Updates (10 min)
    NTP_TZ_OFFSET = 1               # Zeitzone: 1 = CET (Oesterreich/Deutschland)

# === WIFI EINSTELLUNGEN ===
class WiFiConfig:
    # Kein Fallback-Netzwerk – Verbindung nur über gespeicherte Credentials
    # (via Setup-Wizard verbinden, wird in /data/wifi.json gespeichert)
    XOR_KEY = 42  # Schlüssel für XOR+Base64-Obfuskierung der gespeicherten Credentials
